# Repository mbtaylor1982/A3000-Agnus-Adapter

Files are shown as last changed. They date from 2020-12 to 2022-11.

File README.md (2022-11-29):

# A3000-Agnus-Adapter

## Intoduction
With the 8372B Agnus being a rare and expensive beast this adator was designed to allow the use of the relativly common 390544 (8375) 2MB Agnus from the A500+ and A600 in the A3000. 

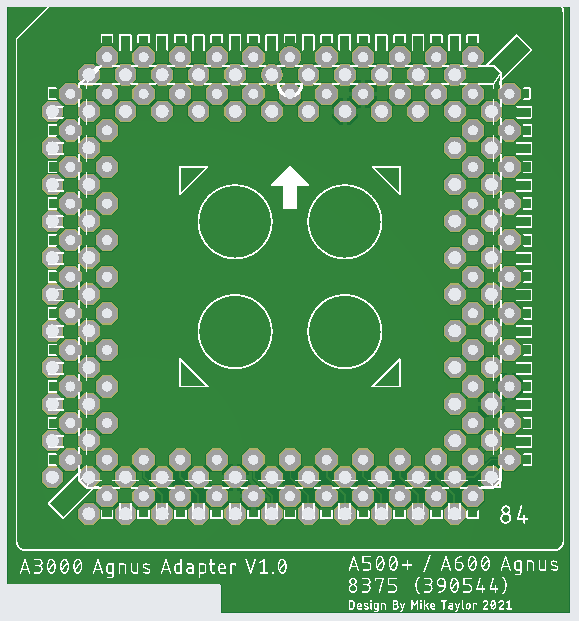
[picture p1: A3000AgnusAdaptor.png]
A3000AgnusAdaptor

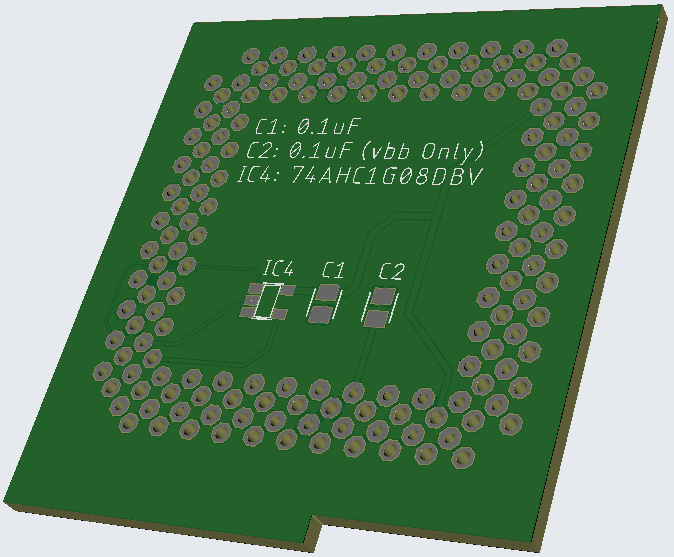
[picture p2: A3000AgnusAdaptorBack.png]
A3000AgnusAdaptorBack

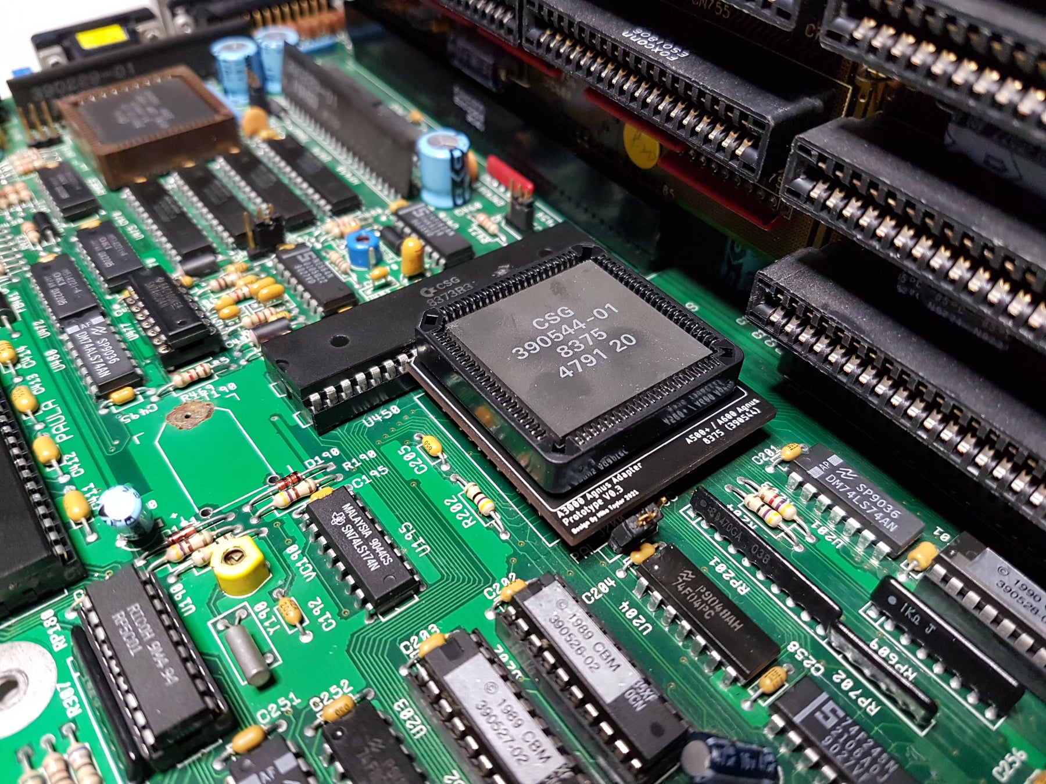
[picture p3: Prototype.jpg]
Prototype

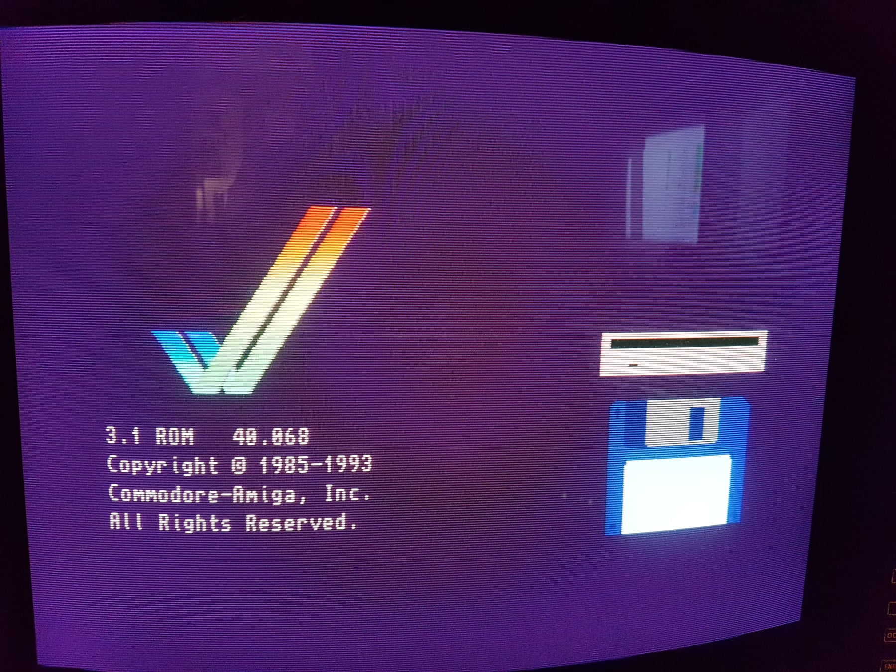
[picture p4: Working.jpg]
Working


## PAL or NTSC
Unlike the 8372B which can be changed between NTSC and PAL with a jumper, the 8375 (390544) can not. 

When selecting an Agnus chip to use with this adaptor there are two choices that have been tested:

1. 390544-01 PAL 2MB Agnus used in Eurpean A500+ and A600
2. 390544-02 NTSC 2MB Agnus Used in North American A500+ and A600

Other variants of the Agnus chip exist and provision has been made for then Vbb connection on pin 40 (C14M). 

If using one of the chips marked Vbb, C2 should be populated with a 0.1uF ceramic capacitor.

**Please note I have not tested any of the below chip revisions so the following info is provided as-is**

>318069-10
>Several pins have been changed to support the A600. This device supports PAL only - the PAL/_NTSC pad is internally pulled up to Vdd (+5). This part is the new rev of >what was previously called 390554-01, except that Vbb replaces the C14M pin.
>
>318069-11
>This pinout is identical to the -10. However, this device supports NTSC only - the PAL/_NTSC pad is internally connected to GND. This part is the new rev of what was >previously called 390554-02, except that Vbb replaces the C14M pin.
>
>318069-12
>Several pins have been changed to support the A600. This device supports PAL only - the PAL/_NTSC pad is internally pulled up to Vdd (+5). This part is the new rev of >what was previously called 390554-01.
>
>318069-13
>Several pins have been changed to support the A600. This device supports NTSC only - the PAL/_NTSC pad is internally connected to ground. This part is the new rev of >what was previously called 390554-02.

Source of above info > https://www.amigawiki.org/lib/exe/fetch.php?media=de:parts:agnus-history.pdf

## Components

| Component | Location  | Qty | Link |
| --- | --- | --- | ---- |
| Ceramic Capacitor, 0.1uF, 0805 | C1, C2 | 2 |  [Mouser](https://www.mouser.com/ProductDetail/710-885012207098) |
| 74AHC1G08 Single 2-Input AND Gate, SOT-23-5 | IC4 | 1 |  [Mouser](https://www.mouser.com/ProductDetail/595-SN74AHC1G08DBVR) |
| PLCC 84 THT Socket | | 1 | [Mouser](https://www.mouser.com/ProductDetail/3M-Electronic-Solutions-Division/8484-11B1-RK-TP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) |
|22-Pin, 2 Row Female header||4|[Mouser](https://www.mouser.se/ProductDetail/517-929975-01-11-RK)||
|22-Pin, 2 Row Male header||4|[Mouser](https://www.mouser.se/ProductDetail/649-77313-118-22LF)||

## Thanks
Thankyou to all the people who have helped with this project.

- Tristan Zondag for testing the adaptor (1st person to get it fully working)
- [Matt Harlum Liv2](https://github.com/LIV2) RAS signal combining inspired by the [A500-2Meg-Chip-ram](https://github.com/LIV2/A500-2Meg-Chip-ram) project.
- [John Chucky Hertell](https://github.com/ChuckyGang) & Peter Mulholland, initial conversations about the idea of using an A500+ Agnus.

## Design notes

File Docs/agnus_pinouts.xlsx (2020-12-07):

PinNo | A500+ / A600 | A3000
1 | DRD_13 | DRD_13
2 | DRD_12 | DRD_12
3 | DRD_11 | DRD_11
4 | DRD_10 | DRD_10
5 | DRD_9 | DRD_9
6 | DRD_8 | DRD_8
7 | DRD_7 | DRD_7
8 | DRD_6 | DRD_6
9 | DRD_5 | DRD_5
10 | DRD_4 | DRD_4
11 | DRD_3 | DRD_3
12 | DRD_2 | DRD_2
13 | DRD_1 | DRD_1
14 | DRD_0 | DRD_0
15 | VCC | VCC
16 | _RST | _RST
17 | _INT3 | _INT3
18 | DMAL | DMAL
19 | _BLISS | _BLISS
20 | _BLIT | _BLIT
21 | _WE | _WE
22 | R_W | R_W
23 | _REGEN | _REGEN
24 | _AS | _AS
25 | _RAMEN | _RAMEN
26 | RGA_8 | RGA_8
27 | RGA_7 | RGA_7
28 | RGA_6 | RGA_6
29 | RGA_5 | RGA_5
30 | RGA_4 | RGA_4
31 | RGA_3 | RGA_3
32 | RGA_2 | RGA_2
33 | RGA_1 | RGA_1
34 | 28MHz Clk | 28MHz Clk
35 | A_20 | A_20
36 | _CDAC | _XCLKEN (VCC in A3000)
37 | 7MHz Clk | _CDAC
38 | CCKQ | 7MHz Clk
39 | CCK | CCKQ
40 | 14M (A500+ NC) | CCK
41 | GND | TST (PAL/NTSC) GND = PAL
42 | DRA_0 | GND
43 | DRA_1 | DRA_0
44 | DRA_2 | DRA_1
45 | DRA_3 | DRA_2
46 | DRA_4 | DRA_3
47 | DRA_5 | DRA_4
48 | DRA_6 | DRA_5
49 | DRA_7 | DRA_6
50 | DRA_8 | DRA_7
51 | _LDS | DRA_8
52 | _UDS | _LDS
53 | _CASL | _UDS
54 | _CASU | _CASL
55 | DRA_9 | _CASU
56 | _RAS_1 | DRA_9
57 | _RAS_0 | _RAS
58 | GND | GND
59 | A_19 | A_19
60 | A_1 | A_1
61 | A_2 | A_2
62 | A_3 | A_3
63 | A_4 | A_4
64 | A_5 | A_5
65 | A_6 | A_6
66 | A_7 | A_7
67 | A_8 | A_8
68 | A_9 | A_9
69 | A_10 | A_10
70 | A_11 | A_11
71 | A_12 | A_12
72 | A_13 | A_13
73 | A_14 | A_14
74 | A_15 | A_15
75 | A_16 | A_16
76 | A_17 | A_17
77 | A_18 | A_18
78 | _LPEN | _LPEN
79 | _VSYNC | _VSYNC
80 | _CSYNCH | _CSYNCH
81 | _HSYNCH | _HSYNCH
82 | GND | GND
83 | DRD_15 | DRD_15
84 | DRD_14 | DRD_14

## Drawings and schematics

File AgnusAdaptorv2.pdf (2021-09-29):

9/29/2021 10:04 PM C:\Users\mike\Documents\EAGLE\projects\A3000 Agnus Adaptor\AgnusAdaptorv2.sch (Sheet: 1/1)

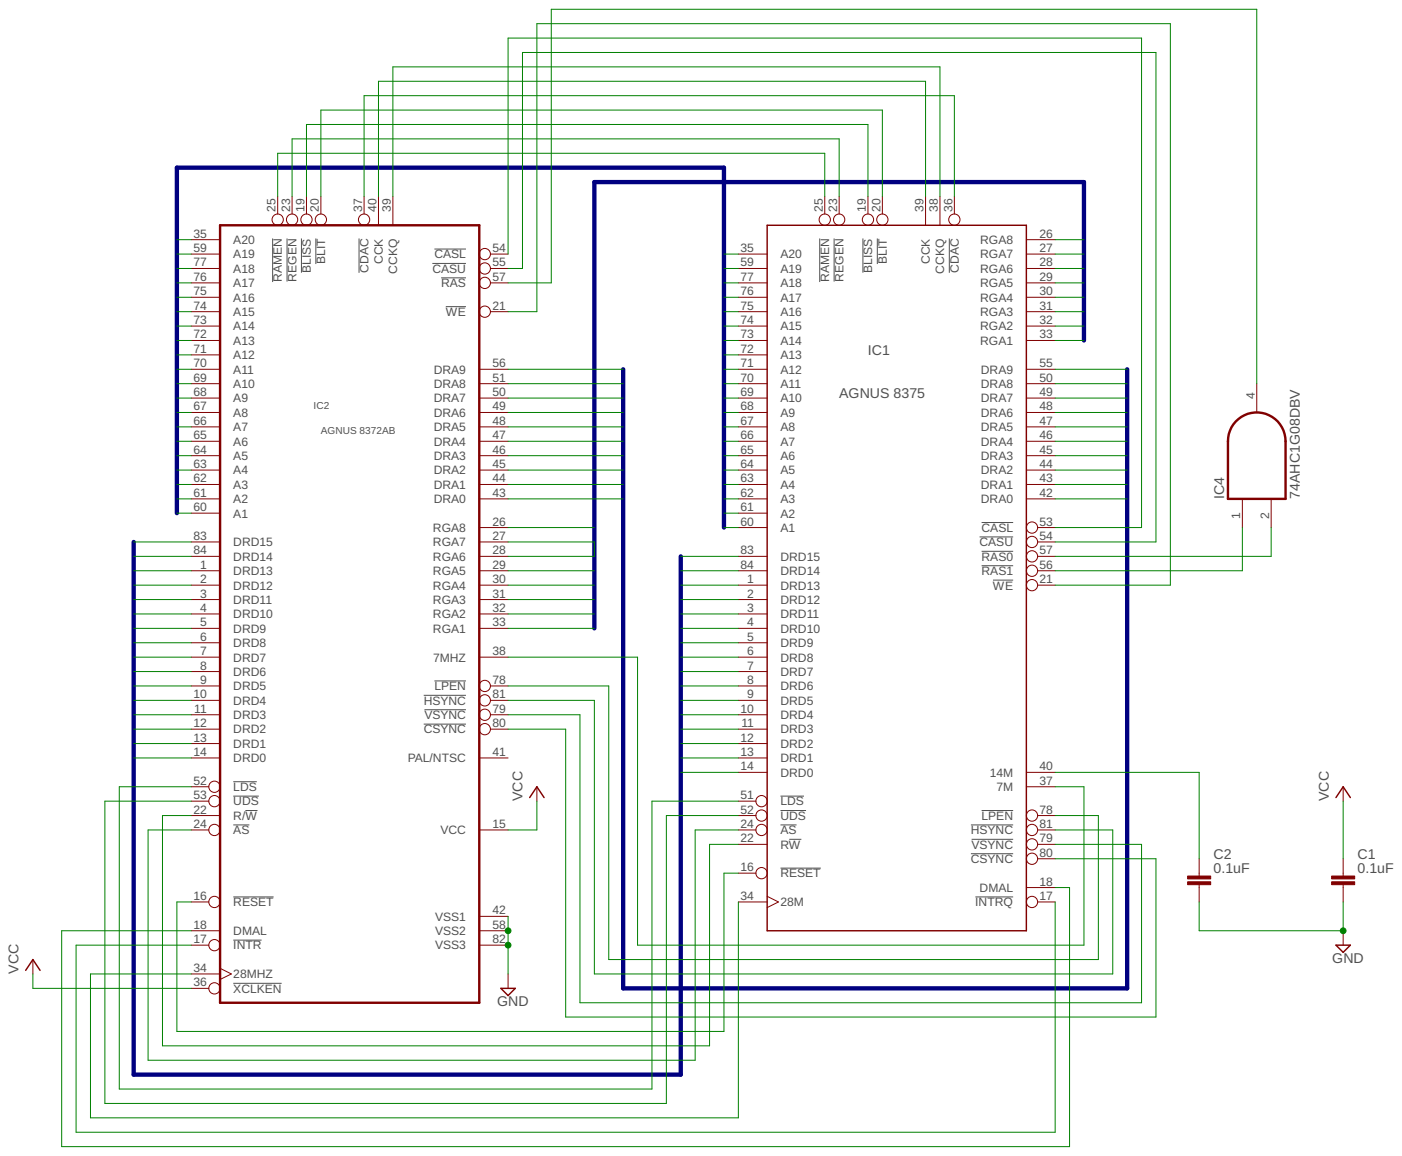
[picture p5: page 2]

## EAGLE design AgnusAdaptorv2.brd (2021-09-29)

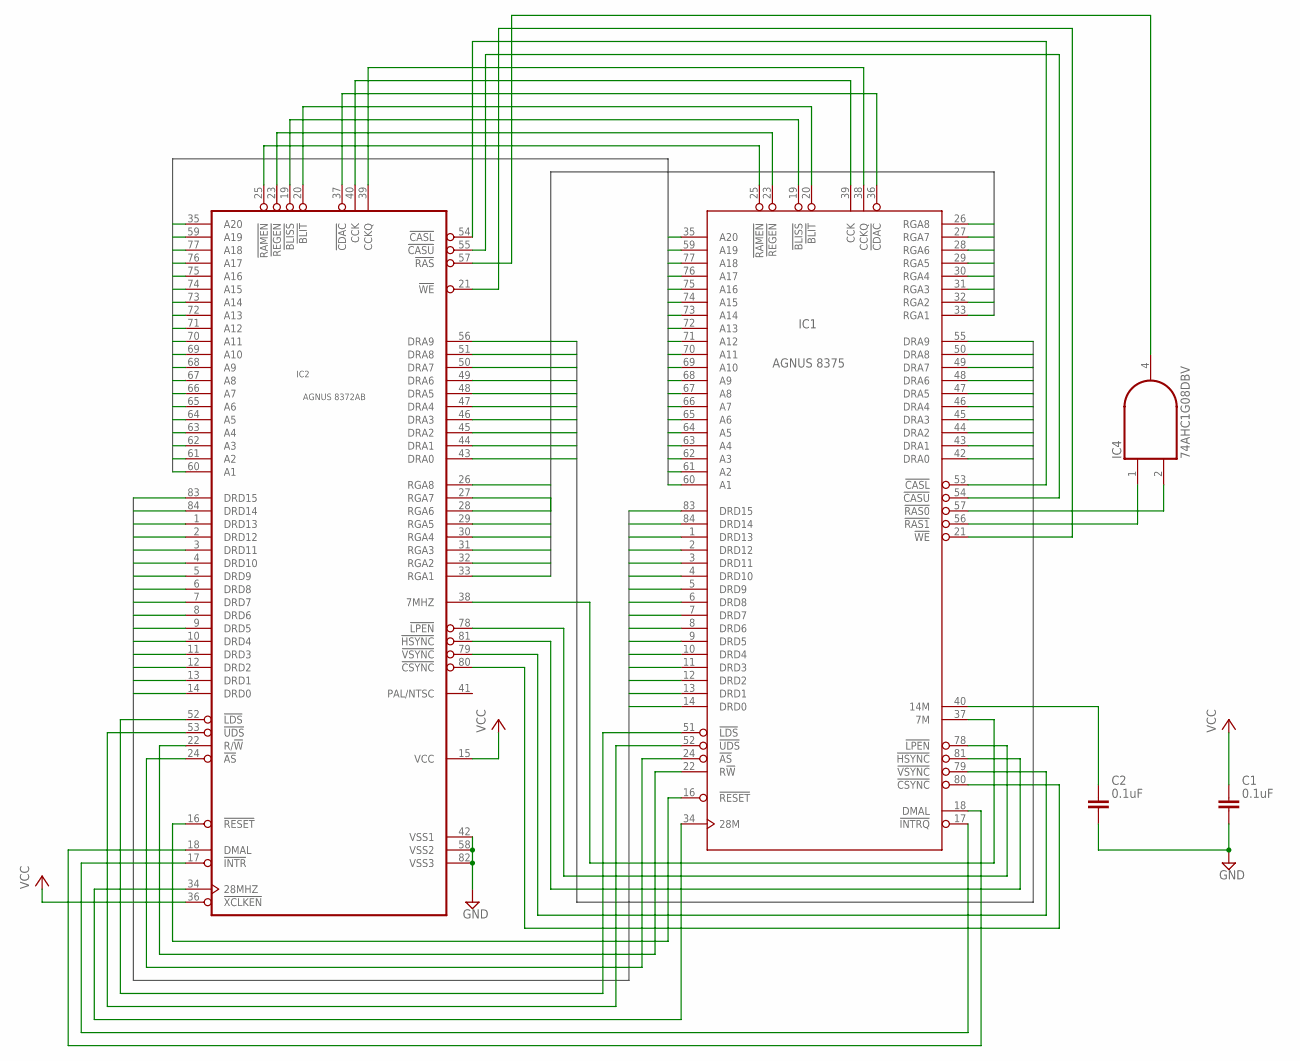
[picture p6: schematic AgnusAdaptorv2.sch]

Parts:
C1, C2: 0.1uF; CAPC2012X110
IC1: AGNUS_8375_A500+_A600_THT; PLCC84_T
IC2: A3000 Agnus Socket; PLCC84_T_H
IC4: 74AHC1G08DBV; SOT23-5

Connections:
7MHZ: IC1.37 (7M), IC2.38 (7MHZ)
28MHZ: IC1.34 (28M), IC2.34 (28MHZ)
!AS: IC1.24 (!AS), IC2.24 (!AS)
!BLISS: IC1.19 (!BLISS), IC2.19 (!BLISS)
!BLIT: IC1.20 (!BLIT), IC2.20 (!BLIT)
!CASL: IC1.53 (!CASL), IC2.54 (!CASL)
!CASU: IC1.54 (!CASU), IC2.55 (!CASU)
!CDAC: IC1.36 (!CDAC), IC2.37 (!CDAC)
!CSYNC: IC1.80 (!CSYNC), IC2.80 (!CSYNC)
!HSYNC: IC1.81 (!HSYNC), IC2.81 (!HSYNC)
!INTRQ: IC1.17 (!INTRQ), IC2.17 (!INTR)
!LDS: IC1.51 (!LDS), IC2.52 (!LDS)
!LPEN: IC1.78 (!LPEN), IC2.78 (!LPEN)
!RAMEN: IC1.25 (!RAMEN), IC2.25 (!RAMEN)
!RAS: IC2.57 (!RAS), IC4.4 (O)
!RAS0: IC1.57 (!RAS0), IC4.2 (I1)
!RAS1: IC1.56 (!RAS1), IC4.1 (I0)
!REGEN: IC1.23 (!REGEN), IC2.23 (!REGEN)
!RESET: IC1.16 (!RESET), IC2.16 (!RESET)
!UDS: IC1.52 (!UDS), IC2.53 (!UDS)
!VSYNC: IC1.79 (!VSYNC), IC2.79 (!VSYNC)
!WE: IC1.21 (!WE), IC2.21 (!WE)
A1: IC1.60 (A1), IC2.60 (A1)
A2: IC1.61 (A2), IC2.61 (A2)
A3: IC1.62 (A3), IC2.62 (A3)
A4: IC1.63 (A4), IC2.63 (A4)
A5: IC1.64 (A5), IC2.64 (A5)
A6: IC1.65 (A6), IC2.65 (A6)
A7: IC1.66 (A7), IC2.66 (A7)
A8: IC1.67 (A8), IC2.67 (A8)
A9: IC1.68 (A9), IC2.68 (A9)
A10: IC1.69 (A10), IC2.69 (A10)
A11: IC1.70 (A11), IC2.70 (A11)
A12: IC1.71 (A12), IC2.71 (A12)
A13: IC1.72 (A13), IC2.72 (A13)
A14: IC1.73 (A14), IC2.73 (A14)
A15: IC1.74 (A15), IC2.74 (A15)
A16: IC1.75 (A16), IC2.75 (A16)
A17: IC1.76 (A17), IC2.76 (A17)
A18: IC1.77 (A18), IC2.77 (A18)
A19: IC1.59 (A19), IC2.59 (A19)
A20: IC1.35 (A20), IC2.35 (A20)
CCK: IC1.39 (CCK), IC2.40 (CCK)
CCKQ: IC1.38 (CCKQ), IC2.39 (CCKQ)
DMAL: IC1.18 (DMAL), IC2.18 (DMAL)
DRA0: IC1.42 (DRA0), IC2.43 (DRA0)
DRA1: IC1.43 (DRA1), IC2.44 (DRA1)
DRA2: IC1.44 (DRA2), IC2.45 (DRA2)
DRA3: IC1.45 (DRA3), IC2.46 (DRA3)
DRA4: IC1.46 (DRA4), IC2.47 (DRA4)
DRA5: IC1.47 (DRA5), IC2.48 (DRA5)
DRA6: IC1.48 (DRA6), IC2.49 (DRA6)
DRA7: IC1.49 (DRA7), IC2.50 (DRA7)
DRA8: IC1.50 (DRA8), IC2.51 (DRA8)
DRA9: IC1.55 (DRA9), IC2.56 (DRA9)
DRD0: IC1.14 (DRD0), IC2.14 (DRD0)
DRD1: IC1.13 (DRD1), IC2.13 (DRD1)
DRD2: IC1.12 (DRD2), IC2.12 (DRD2)
DRD3: IC1.11 (DRD3), IC2.11 (DRD3)
DRD4: IC1.10 (DRD4), IC2.10 (DRD4)
DRD5: IC1.9 (DRD5), IC2.9 (DRD5)
DRD6: IC1.8 (DRD6), IC2.8 (DRD6)
DRD7: IC1.7 (DRD7), IC2.7 (DRD7)
DRD8: IC1.6 (DRD8), IC2.6 (DRD8)
DRD9: IC1.5 (DRD9), IC2.5 (DRD9)
DRD10: IC1.4 (DRD10), IC2.4 (DRD10)
DRD11: IC1.3 (DRD11), IC2.3 (DRD11)
DRD12: IC1.2 (DRD12), IC2.2 (DRD12)
DRD13: IC1.1 (DRD13), IC2.1 (DRD13)
DRD14: IC1.84 (DRD14), IC2.84 (DRD14)
DRD15: IC1.83 (DRD15), IC2.83 (DRD15)
GND: C1.2, C2.2, IC1.41 (GND), IC1.58 (GND), IC1.82 (GND), IC2.42 (VSS1), IC2.58 (VSS2), IC2.82 (VSS3), IC4.3 (GND)
unnamed: C2.1, IC1.40 (14M)
R!W: IC1.22 (R!W), IC2.22 (R/!W!)
RGA1: IC1.33 (RGA1), IC2.33 (RGA1)
RGA2: IC1.32 (RGA2), IC2.32 (RGA2)
RGA3: IC1.31 (RGA3), IC2.31 (RGA3)
RGA4: IC1.30 (RGA4), IC2.30 (RGA4)
RGA5: IC1.29 (RGA5), IC2.29 (RGA5)
RGA6: IC1.28 (RGA6), IC2.28 (RGA6)
RGA7: IC1.27 (RGA7), IC2.27 (RGA7)
RGA8: IC1.26 (RGA8), IC2.26 (RGA8)
VCC: C1.1, IC1.15 (VCC), IC2.15 (VCC), IC2.36 (!XCLKEN), IC4.5 (VCC)

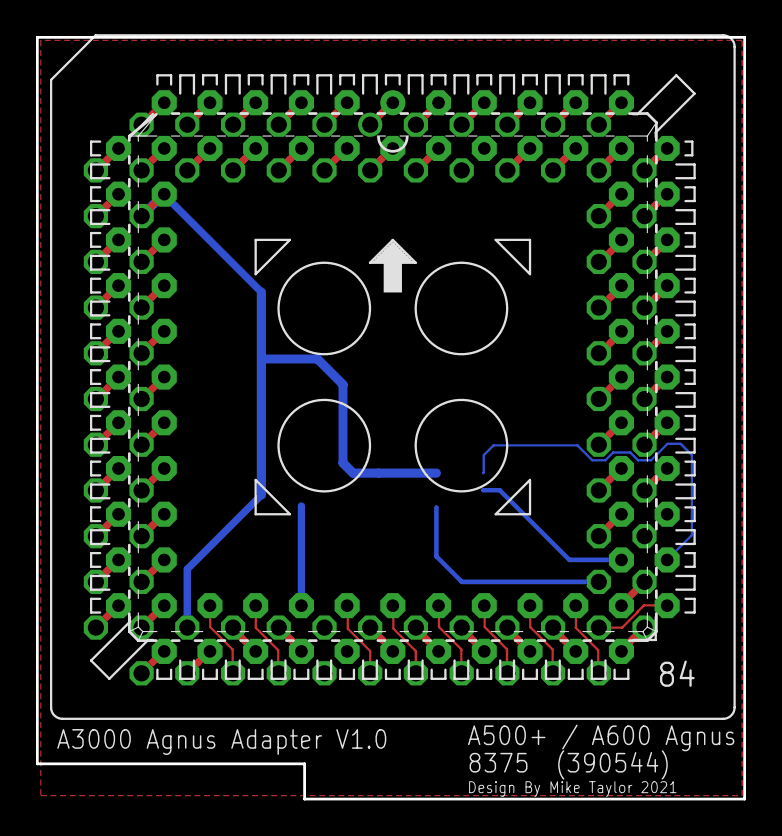
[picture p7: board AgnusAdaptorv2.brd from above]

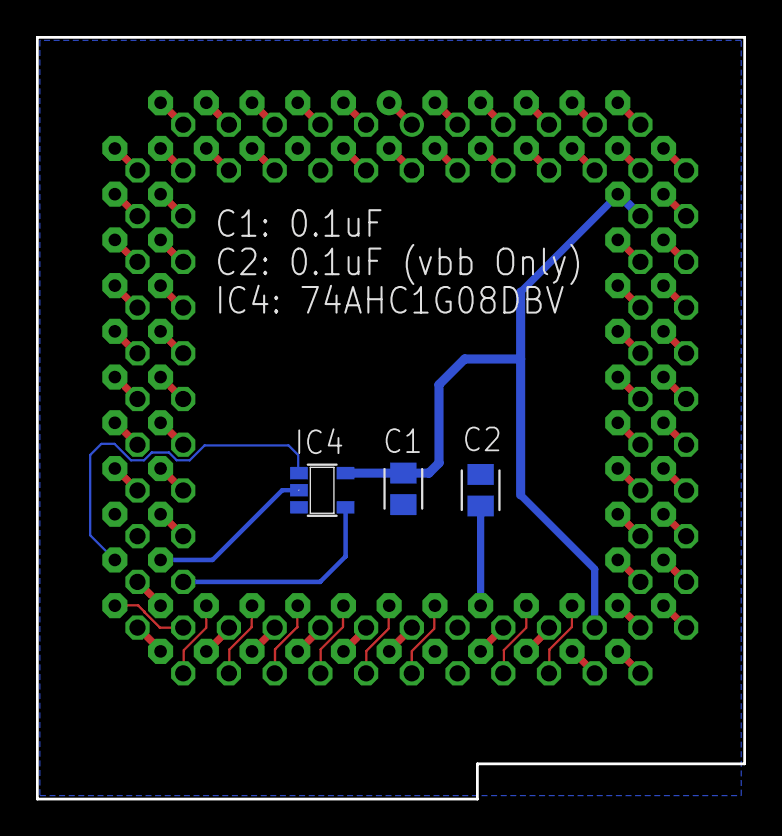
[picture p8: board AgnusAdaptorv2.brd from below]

Board: 2 copper layers, 39.3 x 42.3 mm, 5 parts (3 on the bottom side), 83 nets.

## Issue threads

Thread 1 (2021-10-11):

Could you add photos of the pins used?

ogg1e, 2021-10-11:
I'm not sure what type of header pins to use on the bottom side of this.   Could you add a description and/or photo? Or a mouser link to them?

I think you also might want to add the plcc84 socket to the list as well.  This should be the correct one:
https://www.mouser.com/ProductDetail/3M-Electronic-Solutions-Division/8484-11B1-RK-TP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

mbtaylor1982, 2022-05-30:
These are the pins I use, I actually tack them in from the top side of the board before adding the PLCC socket.
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

after soldering the socket a solder the next rows of header pins and slide the black plastic back down after soldering them in from the underside.

olDirdey, 2022-08-18:
it´s cheaper just to buy a 8372b than soldering this thing.

mbtaylor1982, 2022-08-19:
@olDirdey yeah I admit it is not the easiest project to solder but it's compact and you can fit it to the board and still use the bottom Zorro slot on the riser card.

mbtaylor1982, 2022-11-29:
Pin headers and socket are now added to the BOM in Readme.md

Closed 2022-11-29.

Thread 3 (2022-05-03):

Compatibility with an NTSC 318069?

ogg1e, 2022-05-03:
Do we know if we can use a VBB 318069-11 agnus with this?

mbtaylor1982, 2022-05-30:
Provision has been Made for Vbb on pin 40 (**C14M**). When using one of the below parts marked Vbb **C2** should be populated with a 0.1uF ceramic capacitor.  Please note i do not have one of these chips so have not been able to test it.

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

Source of above info > [https://www.amigawiki.org/lib/exe/fetch.php?media=de:parts:agnus-history.pdf](https://www.amigawiki.org/lib/exe/fetch.php?media=de:parts:agnus-history.pdf)

Closed 2022-05-30.

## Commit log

2020-12-04 Add files via upload
    Initial commit
    [AgnusAdaptor.brd, AgnusAdaptor.sch]
2020-12-07 first go at routing complete
    [AgnusAdaptor.brd, AgnusAdaptor.sch]
2020-12-07 fixed back annotation issue in board and added docs and libs
    [AgnusAdaptor.brd, AgnusAdaptorEagle7.brd, AgnusAdaptorEagle7.sch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]
2021-09-29 Removed old files
    [AgnusAdaptor.brd, AgnusAdaptor.sch, AgnusAdaptorEagle7.brd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]
2021-09-29 uploading tested first version
    [AgnusAdaptorv2.brd, AgnusAdaptorv2.sch]
2022-06-09 added PLCC 84 socket to Component list
2022-11-29 Update to Readme.md to add pin headers to the BOM
